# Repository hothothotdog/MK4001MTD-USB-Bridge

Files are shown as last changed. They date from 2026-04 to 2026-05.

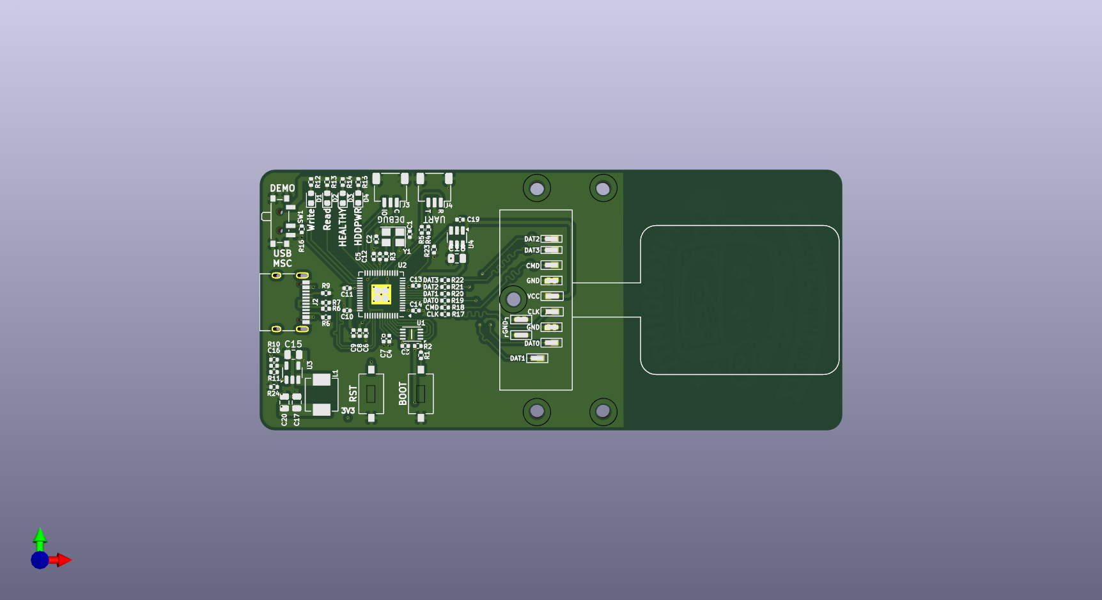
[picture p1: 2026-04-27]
hardware/MK4001MTD_3D-f.png

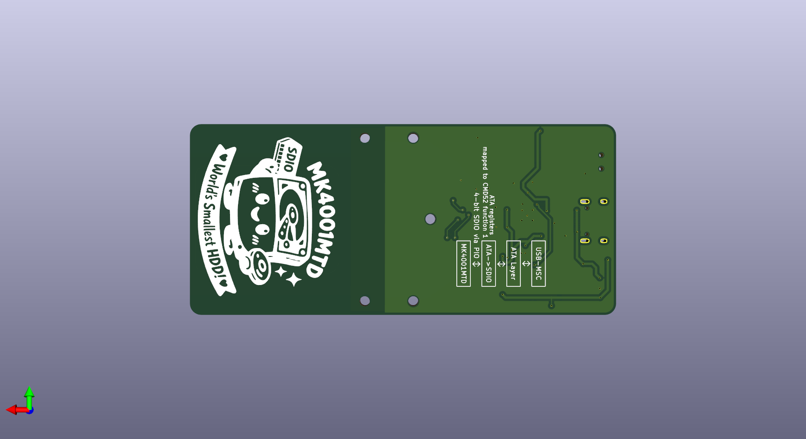
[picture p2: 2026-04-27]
hardware/MK4001MTD_3D-B.png

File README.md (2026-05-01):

This repository has moved to [https://codeberg.org/hothothotdog/MK4001MTD-USB-Bridge](https://codeberg.org/hothothotdog/MK4001MTD-USB-Bridge)

This GitHub copy is a frozen archive. New commits, issues, and pull requests should go to Codeberg.

---

Budget friendly changes to the PCB. Modified the PCB from 4-layers and 11cm long (about $70) to under 10cm and 2-layers which puts this in the $5 cost range at jlcpcb 

Schematic changes:
   - TLV62569DBV 
   Filter caps changed to higher value (as per datasheet recommendation)
   Voltage divider changed from 112K 25.3K (3.2v out) to sensible values 270K 60K (3.33v out)
   - Leds
   Current limiters set to 1mA (plenty bright enough)
   - Crystal 12MHz
   Changed 27pf caps to correct capacitance of 10pF each
   - NOR Flash
   Changed part to correct winbond W25Q16JVUXIQ
   Package changed to the correct DFN 3x2mm 

   new kicad files uploaded (27-4-2026) + ibom + images + pdf
   
# MK4001MTD USB Bridge

**RP2040 Pico firmware that bridges a Toshiba MK4001MTD 0.85" SDIO microdrive as a USB Mass Storage device.**
_DSC1170
_DSC1354

The MK4001MTD is a 4 GB Microdrive originally used in the Nokia N91 music phone and some other devices, like MP3 players or USB drives, back when flash storage was still quite expensive.

You might have seen introductions claiming this drive uses the MMC protocol, but that’s actually incorrect. I’ve been investigating this for a while: I tried building an 8-bit MMCplus card reader and tested different SD/MMC readers without success. As a last resort, I bought a Nokia N91 to capture logic traces and confirm what protocol it actually uses.

Here is the photo when I was trying to use it with my 8bit-MMCPlus reader board, and it turns out it is not MMC :(
_DSC0484

So I end up getting N91 to collect traces:
_DSC1093
_DSC1131

Unlike standard ATA/CF Microdrives, it uses an SDIO interface with ATA commands tunneled through CMD52/CMD53. No existing driver supports this protocol, so this firmware implements the full stack from scratch.

This surprised me, because there is an SDIO-to-ATA standard called CE-ATA. But if you look closely at the release timeline, CE-ATA came later than this drive. As a result, this drive relies entirely on SDIO commands, and CE-ATA is not available. CE-ATA has two new cmd CMD60/CMD61 and utilize CMD12/39, but you can see from the traces it is not using any of those.  

The second hardware point to mention is that another piece of misinformation floating around—claiming it’s an 8-bit MMCPlus card—is not only untrue, but the pinout doesn’t follow the MMC standard either. You can find the Nokia N91 service manual with some documentation on the pinout: while the pin numbering follows the MMCPlus standard, the pin mapping does not. This is an important detail if you’re wiring it yourself: it uses the same MMC connector, but the pin mapping is different, more in the Hardware section.

Finally, note that this is co-developed with Claude/OpenClaw. I collected the logic traces manually and set up a closed-loop test station for OpenClaw to iterate on development—analyzing the traces and implementing features. The documentation will mostly be written by Claude; I’ll add my notes inline as well. I’ve also read and double-checked the documentation myself, and it should be reliable and easy to follow.

For insights into the analytics on N91 trace, it is under /docs/N91_TRACE_ANALYSIS.md, I've also put the N91 service manual there along with the raw logic traces.

See more in the blog post here: [https://www.willwhang.dev/Reading-MK4001MTD/](https://www.willwhang.dev/Reading-MK4001MTD/)  
See it in activity here: [https://youtu.be/GC4xil3_Bbc](https://youtu.be/GC4xil3_Bbc)

## Status

Fully functional USB mass storage with PIO-accelerated reads/writes and idle power management.

| Metric | Value |
|---|---|
| Read speed | 550 kB/s |
| Write speed | 364 kB/s |
| Capacity | 3.75 GB (7,862,400 sectors) |
| Filesystem | FAT32 verified (mount/unmount/fsck clean) |
| Data integrity | Write+readback MD5 verified |
| Idle standby | 1 second timeout → STANDBY IMMEDIATE |

## How It Works

### Architecture

```
USB Host ←→ USB MSC (TinyUSB) ←→ ATA Layer ←→ SDIO Layer (PIO) ←→ MK4001MTD
```

The firmware has four layers:

1. **USB MSC** (`msc_device.c`) — TinyUSB Mass Storage Class. Translates SCSI READ(10)/WRITE(10) into ATA sector operations. EP buffer is 8192 bytes, batching up to 16 sectors per USB transfer. Activity LEDs on GP9 (TX/write) and GP10 (RX/read). Tracks last I/O timestamp for idle power management.

2. **ATA-over-SDIO** (`ata_sdio.c`) — Implements ATA commands (IDENTIFY, READ SECTORS, WRITE SECTORS) by writing to ATA registers mapped into SDIO function 1 address space via CMD52, and transferring sector data via CMD53. 3-tier retry logic at CMD, data, and ATA levels.

3. **PIO SDIO** (`sdio_pio.c`, `sdio.pio`) — Hardware-accelerated SDIO using RP2040's PIO peripheral. Three PIO programs share a single state machine via dynamic program swapping:
   - **CMD tx/rx** (26 instructions) — sends SDIO commands and receives responses
   - **DAT read** (13 instructions) — reads data blocks from 4-bit DAT bus via DMA
   - **DAT write** (16 instructions) — writes data blocks to 4-bit DAT bus via DMA, with built-in CRC status reception and busy-wait

4. **Bit-bang SDIO** (`sdio_hw.c`) — Software SDIO used only for card initialization at 400 KHz (before PIO is set up). All runtime I/O uses PIO.

Human notes: Interestingly, Claude was really reluctant to implement SDIO in PIO, and a lot of development cycles were wasted bouncing back and forth between PIO and bit-banging.

### The SDIO-ATA Protocol

The MK4001MTD presents itself as an SDIO card with one I/O function. Standard SDIO card initialization (CMD5/CMD3/CMD7) sets up the bus, then ATA registers are accessed through SDIO commands:

**Register access (CMD52):** Each ATA register is mapped to a function 1 address:

| Address | Register | Usage |
|---|---|---|
| 0x00 | DATA | CMD53 target for sector data |
| 0x01 | ERR/FEAT | Error (read) / Feature (write) |
| 0x02 | SECCOUNT | Sector count |
| 0x03 | LBA_LO | LBA bits 0-7 |
| 0x04 | LBA_MID | LBA bits 8-15 |
| 0x05 | LBA_HI | LBA bits 16-23 |
| 0x06 | DEV/HEAD | Device/Head + LBA bits 24-27 |
| 0x07 | CMD/STATUS | Command (write) / Status (read) |

**Data transfer (CMD53):** Sector data is transferred by issuing CMD53 in block mode targeting the DATA register (address 0x00). For multi-sector reads, a single CMD53 with `block_count=N` transfers N × 512 bytes in one SDIO multi-block transaction.

**Interrupt signaling:** The drive signals sector readiness by asserting an SDIO interrupt (INT_PENDING bit 1 in CCCR register 0x05). Reading the ATA STATUS register clears the interrupt.

### Read Path (Multi-Block PIO)

For a 16-sector read:

```
1. Write ATA registers via PIO CMD52:
     SECCOUNT=16, LBA_LO/MID/HI, DEV/HEAD=0xE0, CMD=0x20

2. Poll STATUS via CMD52 until DRQ (bit 3) is set

3. Swap PIO to DAT read program
4. Send CMD53: block_mode=1, fn=1, addr=0x0000, block_count=16

5. PIO DAT read: for each of the 16 blocks:
   a. Wait for start bit (all DAT lines low)
   b. DMA 1024 nibbles (512 bytes) from PIO RX FIFO to buffer
   c. Wait for SM to finish clocking CRC+end nibbles (poll SM PC)
   d. Repack nibbles → bytes in-place

6. Swap PIO back to CMD program
```

### Write Path (Multi-Block PIO)

For a 16-sector write:

```
1. Write ATA registers via PIO CMD52:
     SECCOUNT=16, LBA, DEV/HEAD=0xE0, CMD=0x30

2. Poll STATUS via CMD52 until DRQ (bit 3) is set
   (STATUS 0xD8 = BSY+DRQ treated as DRQ-ready, per N91 trace)

3. Swap PIO to DAT write program
4. Send CMD53: block_mode=1, fn=1, addr=0x0000, block_count=16

5. PIO DAT write: for each of the 16 blocks:
   a. Precompute CRC16-CCITT per DAT line (4 independent CRCs)
   b. Build nibble stream: start(0x0) + data(1024 nibbles) + CRC(16) + end(0xF)
   c. DMA nibble stream to PIO TX FIFO
   d. PIO clocks out all nibbles, then:
      - Switches DAT to input
      - Clocks 16 cycles for CRC status from card
      - Polls DAT0 until card releases busy
      - Fires IRQ 0 to signal block completion

6. Swap PIO back to CMD program
```

### PIO Program Swapping

The RP2040 PIO has 32 instruction slots per block. Our three programs total 55 instructions, so they can't coexist. Instead, a single SM0 on PIO0 is used, and programs are swapped by writing directly to PIO instruction memory:

```c
static void load_program_raw(const pio_program_t *program) {
    for (uint i = 0; i < program->length; i++)
        pio->instr_mem[FIXED_OFFSET + i] = program->instructions[i];
}
```

This bypasses the SDK's `pio_add_program`/`pio_remove_program` allocator. Program swap takes ~1 µs. Each swap is followed by a program-specific reinit that sets pin mappings, shift direction, and clock divider.

### Power Management

Analysis of Nokia N91 logic traces reveals aggressive power management:

- **Idle mode:** STANDBY IMMEDIATE (0xE0) every **~7.5 seconds**, even with no I/O. Each standby triggers full SDIO re-initialization (CMD5 retry → CMD3 → CMD7 → CCCR setup). 28 standby cycles observed in one idle session.
- **Active mode:** Standby issued between bursts of I/O (24 cycles during USB drive file operations).
- No other power commands (IDLE, SLEEP, CHECK POWER MODE) or CCCR power register accesses observed.

The firmware replicates this behavior with a configurable idle timeout:

```c
#define IDLE_STANDBY_MS 5000  // in main.c
```

Two paths trigger HDD power gating:

1. **Idle timeout** (5 seconds) — main loop detects no I/O activity
2. **USB suspend** — host suspends the USB port

Both paths send ATA STANDBY IMMEDIATE (0xE0) to flush the write cache and park heads, then cut power via GP9.

**Wake sequence** (triggered by first READ/WRITE after gate):
1. Power on HDD, wait 500ms for rail settling
2. PIO-based SDIO reinit: CMD5 (OCR) → 10ms settle → CMD3 (RCA) → CMD7 (select)
3. Switch to fast PIO clock, configure CCCR via CMD52 (4-bit bus, 512B blocks, fn1 enable)
4. Poll fn1 ready (CCCR IO_READY bit 1)
5. N91-style 30ms DRDY status poll until drive is ATA-ready

### Bad Sector Handling

When a multi-sector transfer hits a bad sector:
1. Chunk read fails → error recovery (IO_ABORT + fn1 reset, ~500ms)
2. Falls back to per-sector I/O to identify the failing block precisely
3. The ATA layer waits long enough to capture the final `STATUS/ERROR` bits instead of collapsing the failure into a generic `DRQ timeout`
4. Bad sector LBA cached → subsequent access fails quickly without re-hammering the drive
5. Any unrecovered block fails the SCSI command immediately with `MEDIUM ERROR`

On the known failing root-directory sector (`LBA 1952`), the drive now reports the real ATA result:

```text
READ: ST=0x51 ERR ERR=0x40 UNC LBA=1952
FAST-RD: ST=0x51 ERR ERR=0x40 UNC LBA=1952
```

## Building

### Prerequisites

- Raspberry Pi Pico SDK
- ARM toolchain (`arm-none-eabi-gcc`)
- CMake

### Build & Flash

```bash
cd /home/pi/mk4001_bridge/build
cmake ..
make -j4

sudo openocd -f interface/cmsis-dap.cfg -f target/rp2040.cfg \
  -c "adapter speed 1000" -c "init" -c "reset halt" -c "sleep 200" \
  -c "program /home/pi/mk4001_bridge/build/mk4001_bridge.elf verify" \
  -c "reset run" -c "exit"
```

### Hardware Wiring

| Pico GPIO | Function | Notes |
|---|---|---|
| GP2 | SDIO_CLK | Host clock output |
| GP3 | SDIO_CMD | Bidirectional command line |
| GP4 | SDIO_DAT0 | Data bit 0 |
| GP5 | SDIO_DAT1 | Data bit 1 |
| GP6 | SDIO_DAT2 | Data bit 2 |
| GP7 | SDIO_DAT3 | Data bit 3 |
| GP9 | HDD_EN | Drive power enable (HIGH=on) |
| GP12 | UART TX | Debug output @ 115200 |
| GP13 | UART RX | Debug input |
| GP16 | LED: HDD Power | Active low |
| GP17 | LED: HDD Healthy | Active low |
| GP18 | LED: Read | Active low |
| GP19 | LED: Write | Active low |

**Note:** GP0 and GP1 are dead on this specific Pico unit. All SDIO pin assignments are shifted +2.

Human notes: Claude was wrong here because it didn’t realize that GP0 and GP1 were being used for the UART terminal in its build configuration. It kept forgetting this, to the point where I just moved the SDIO GPIOs off that UART.

HDD_PWR isn’t necessary. You don’t have to power-cycle the drive to use it; it’s more of a development convenience for resetting the HDD when a lot of things are hard-coded. That said, if you want power savings, you can use that signal, but it can handle warm reset without any issue.

You’ll see debug messages over UART. They’re not going through USB-CDC because it was easier for Claude to set up a separate UART-to-USB logging link that doesn’t disconnect or become unstable during early development.  
Here is a example of the log:

```
========================================
  MK4001MTD USB Bridge v0.11
  SDIO-ATA → USB Mass Storage (PIO)
========================================

[MAIN] Pre-delay 5000ms...
[PIO] Init OK: clkdiv=3.12 (~10.0 MHz), CMD@0
[MAIN] Power cycling HDD...
[SDIO] HDD power OFF
[SDIO] HDD power ON
[MAIN] SDIO init (PIO)...
[SDIO] CMD5 ready (OCR=0x901F8000)
[SDIO] RCA=0x0001
[SDIO] fn1 ready (attempt 0)
[MAIN] ATA IDENTIFY...
[ATA] IDENTIFY complete
Model:    [TOSHIBA MK4001MTD]
Serial:   [           763B004HA]
Firmware: [VH173A]
Sectors:  7862400 (3839 MB)
SMART:    not supported (supported=0, enabled=0)
IDENTIFY: W0=0040 W47=0000 W49=0000 W59=0000
  ATA W80=0000  Cmd W82=0000 W83=0000 W84=0000
  En  W85=0000 W86=0000 W87=0000  W89=0008 W128=0001

[DIAG] === Drive Diagnostics ===
[DIAG] Standard SMART: not supported (IDENTIFY W82 bit0 = 0)
[DIAG] Toshiba vendor CMD 0xC2:
  FEAT=0x01 unknown_01                       → SC=00 LBA=02/00/00 ST=50
  FEAT=0x02 unknown_02                       â SC=00 LBA=02/00/00 ST=50
  FEAT=0x03 unknown_03                       → SC=00 LBA=02/00/00 ST=50
  FEAT=0x04 unknown_04                       → SC=00 LBA=02/00/00 ST=50
  FEAT=0x10 diag_10 (LBA_LO varies)          → SC=00 LBA=00/00/00 ST=50
  FEAT=0x11 diag_11                          → SC=00 LBA=00/00/00 ST=50
  FEAT=0x12 diag_12 (LBA_LO varies)          → SC=00 LBA=01/00/00 ST=50
  FEAT=0x20 query_20 (N91: SC=0xFF always)   → SC=FE LBA=00/FF/00 ST=50
  FEAT=0x21 query_21 (N91: SC varies per boot) → SC=1B LBA=00/FF/00 ST=50

[MAIN] MBR: valid 0x55AA
[MAIN] Warming up...
[MAIN] PIO OK, STATUS=0x50
[MAIN] Drive: 7862400 sectors (3839 MB)
[MAIN] Ready.
[PWR] Idle 5000ms → STANDBY + power gate
[PWR] STANDBY IMMEDIATE → power gate
[SDIO] HDD power OFF
```

Finally, here’s the wiring to the actual drive.  
_DSC1176-2
Here is a crop from the N91 schematic, you can map the pin number also.


Side note that this is a 3V drive but I think 3.3V is fine, mostly it is to save some level shifting work.  

HW specifically designed for this drive is under /hardware!


## Source Files

| File | Lines | Purpose |
|---|---|---|
| `main.c` | 210 | Init, idle standby, USB suspend/resume |
| `msc_device.c` | 400 | USB MSC callbacks, power gate wake, bad sector cache |
| `ata_sdio.c` | 390 | ATA commands, error recovery, vendor diagnostics |
| `sdio_pio.c` | 635 | PIO SDIO: CMD52, CMD53 read/write, program swap, CRC16 |
| `sdio_hw.c` | 45 | Pin init + HDD power control |
| `sdio.pio` | 200 | PIO assembly + C SDK init helpers |
| `led.h` | 37 | LED helpers (GP16–GP19, active low) |
| `usb_descriptors.c` | 77 | USB device/config/string descriptors |
| `tusb_config.h` | 20 | TinyUSB config (MSC, 32KB EP buffer) |

## Version History

| Version | Read | Write | Key Change |
|---|---|---|---|
| v0.1–v0.3 | 105 kB/s | 93 kB/s | Bit-bang SDIO, CRC16, retry logic |
| v0.5 | 374 kB/s | — | Single-SM PIO, direct instruction memory swap |
| v0.6 | 583 kB/s | 93 kB/s | Multi-block CMD53 reads, CRC clock drain fix |
| v0.8 | 588 kB/s | 274 kB/s | PIO writes, OSR flush fix |
| v0.9 | 475 kB/s | 371 kB/s | 64-sector chunks, CRC16 read verification |
| v0.10 | 453 kB/s | 329 kB/s | LED remap, HDD EN pin, UART on GP12/GP13 |
| **v0.11** | **~450 kB/s** | **~340 kB/s** | **HDD power gate, PIO wake, bad sector sense, USB suspend** |

## Testing

```bash
# Check device appeared
lsblk -dno NAME,MODEL | grep MK4001

# Filesystem test — mount, copy files, verify
sudo mount /dev/sdX1 /mnt/mk4001
cp /tmp/testfile /mnt/mk4001/
sync
md5sum /tmp/testfile /mnt/mk4001/testfile    # should match
sudo umount /mnt/mk4001

# Speed benchmarks (raw device, do NOT mount first — will corrupt filesystem)
# Use a safe offset past the filesystem or an unpartitioned drive
sudo dd if=/dev/sdX of=/dev/null bs=64k count=128 iflag=direct     # read
sudo dd if=/dev/zero of=/dev/sdX bs=64k count=64 oflag=direct seek=1024  # write (offset past FS)
```

Human notes here, fun fact: When it first starts to do speed testing, it actually dd directly to the drive and damage the filesystems..... Thankfully it doesn't matter that much here during the developments but always keep in mind when you handle OpenClaw your setup.

## License

I don't care.

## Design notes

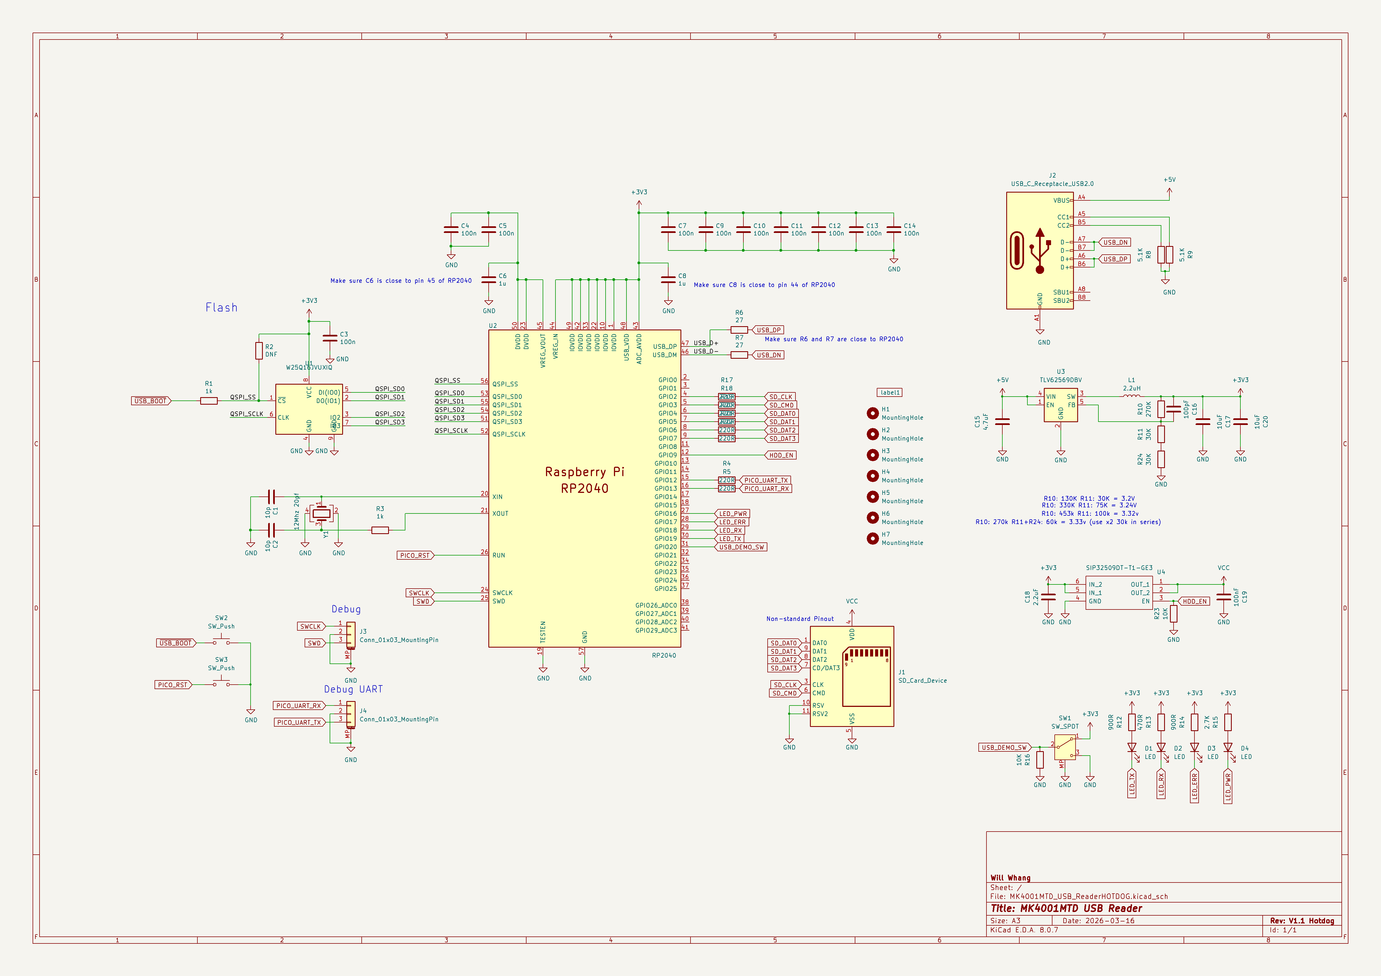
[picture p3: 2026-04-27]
hardware/SCH.png

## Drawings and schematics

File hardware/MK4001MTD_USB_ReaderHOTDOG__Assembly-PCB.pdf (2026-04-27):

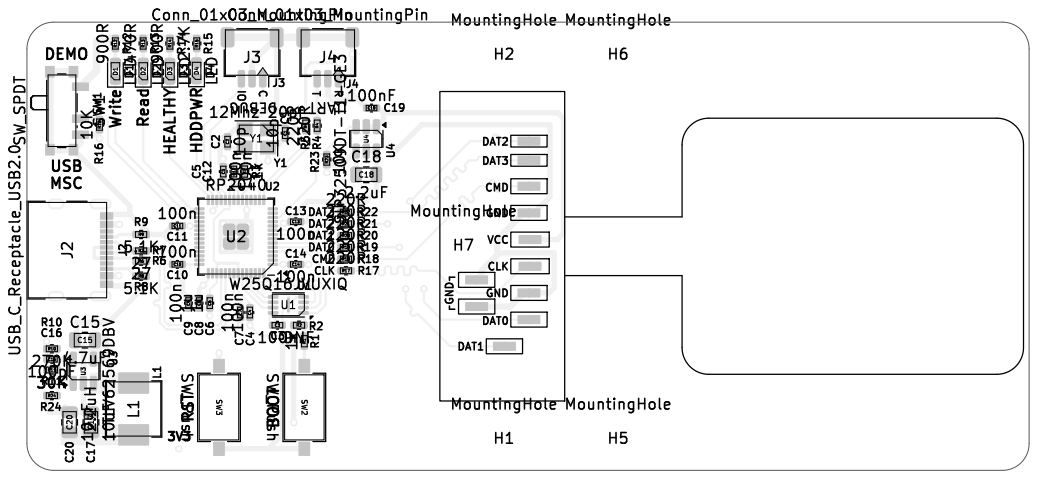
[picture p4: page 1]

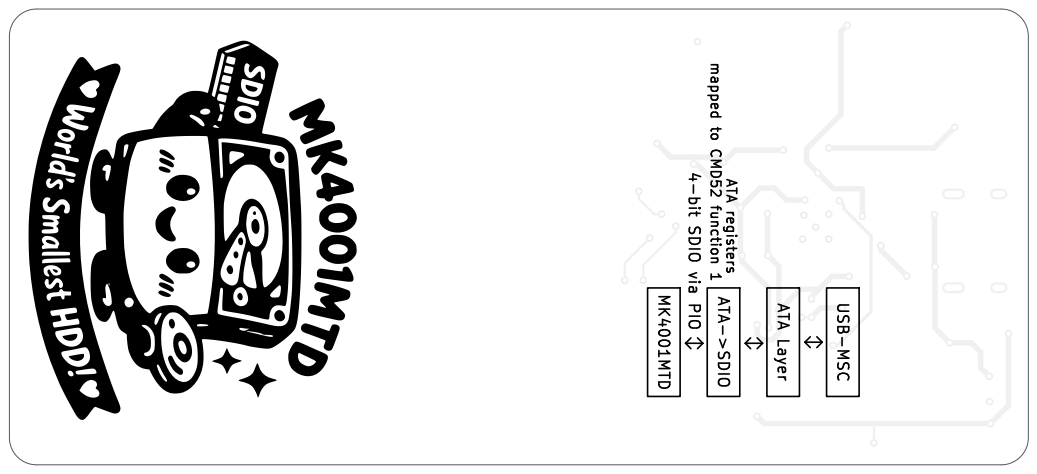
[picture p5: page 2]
D Date: 2026-03-16 KiCad; E.D.A. 8.0.7 Size: A4; Rev: v1.1; HOTDOG; Id: 1/1 Title: MK4001MTD USB Reader File: MK4001MTD_USB_ReaderHOTDOG.kicad_pcb Sheet: Black; And; White; BOT Will Whang Board2Pdf:; Black; BOT -; Page 2/2

USB-MSC ATA registers mapped to CMD52 function 1 ATA Layer MK4001MTD ATA->SDIO 4-bit SDIO via PIO

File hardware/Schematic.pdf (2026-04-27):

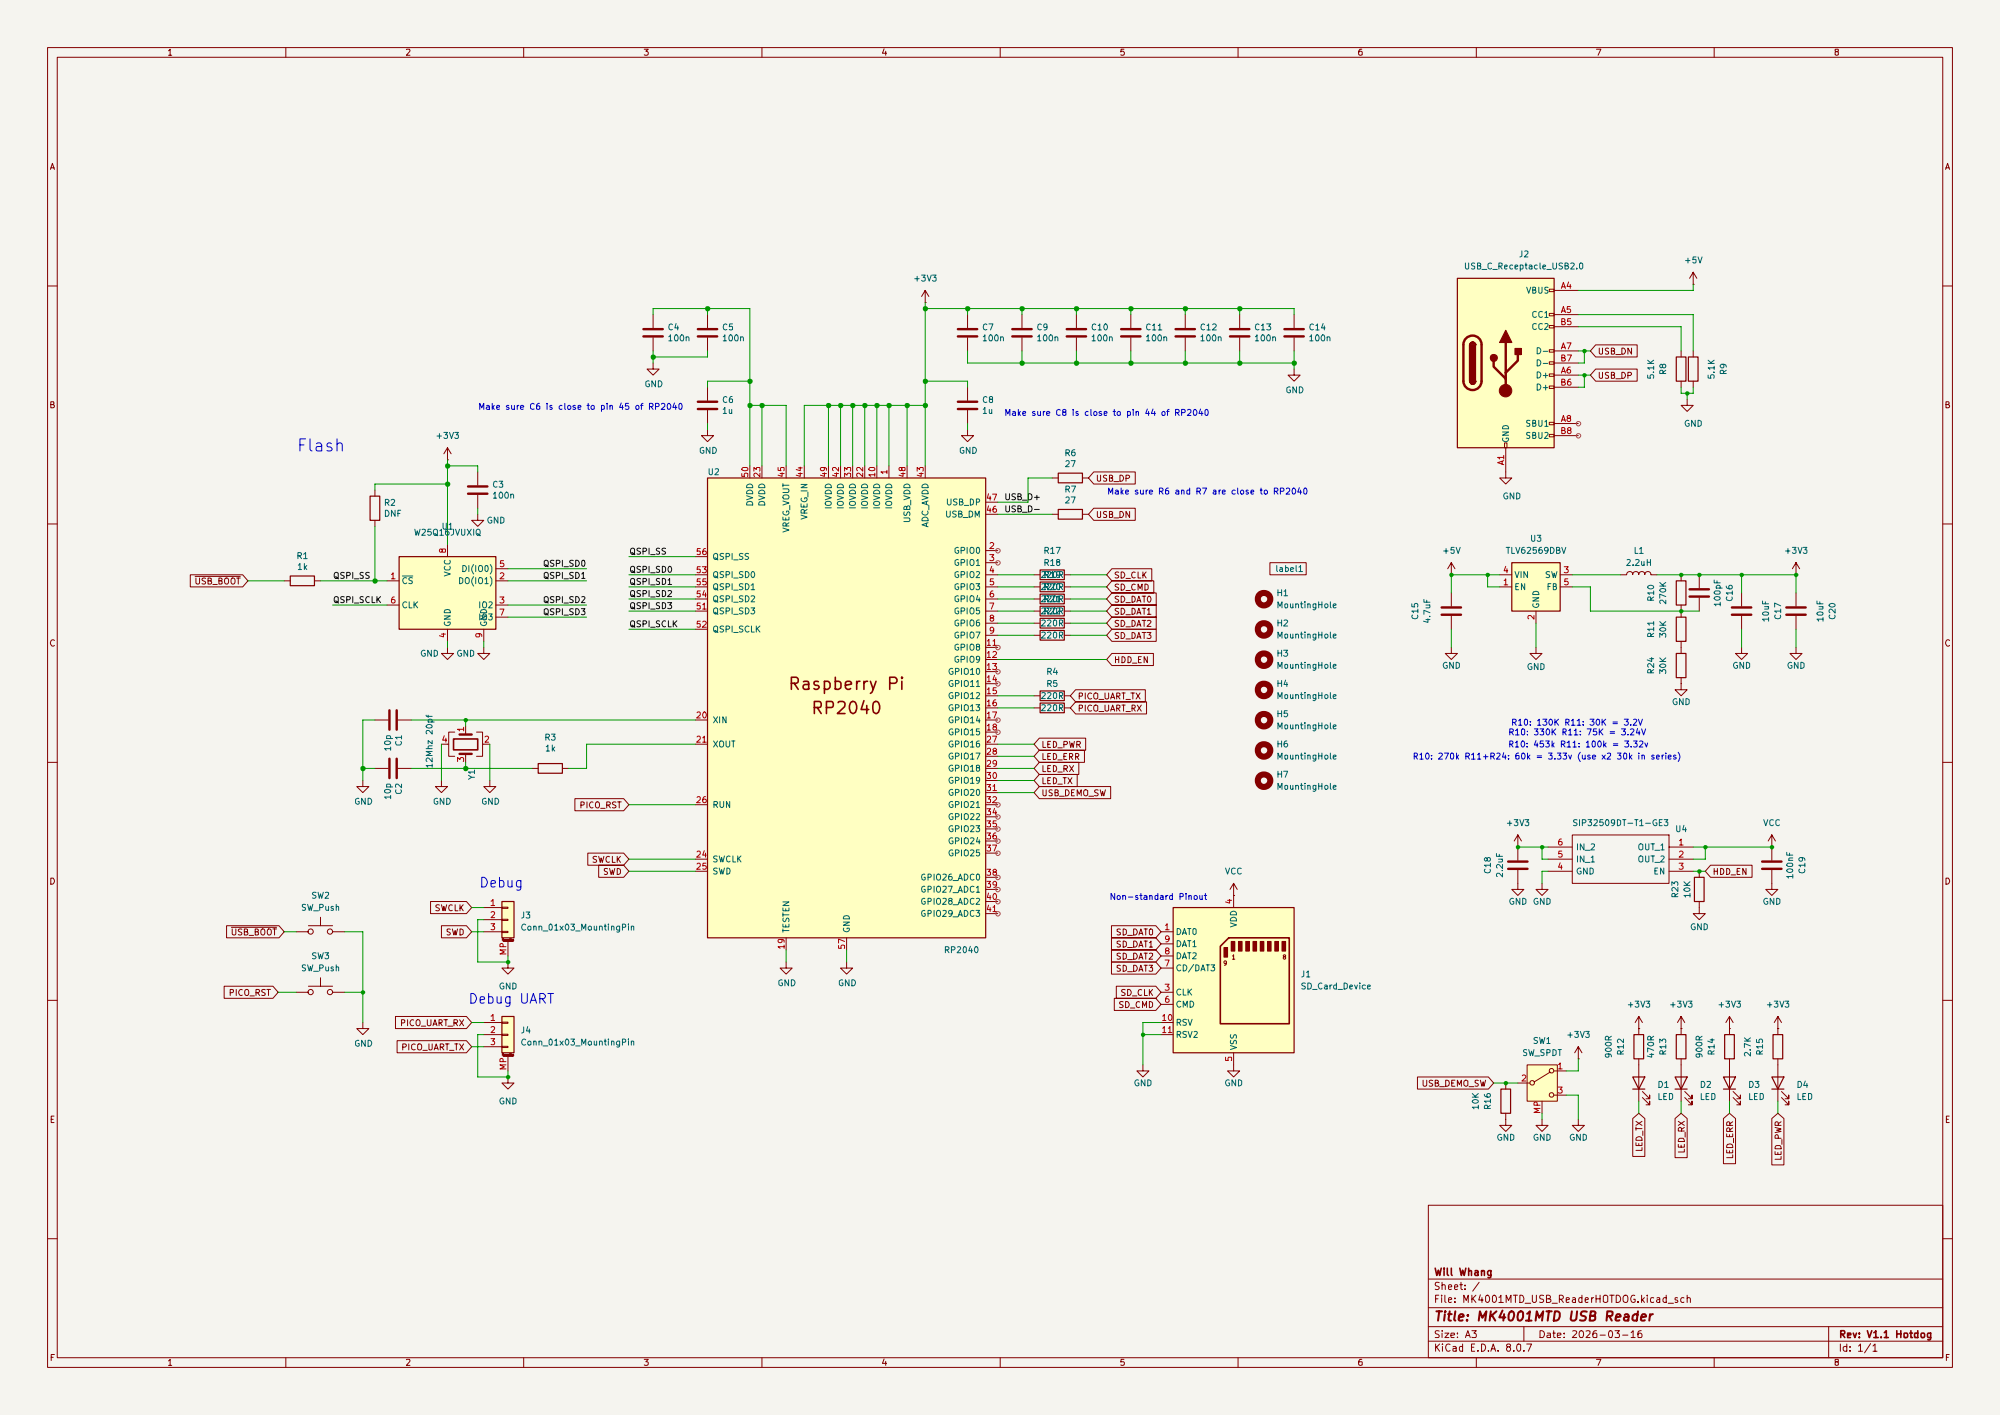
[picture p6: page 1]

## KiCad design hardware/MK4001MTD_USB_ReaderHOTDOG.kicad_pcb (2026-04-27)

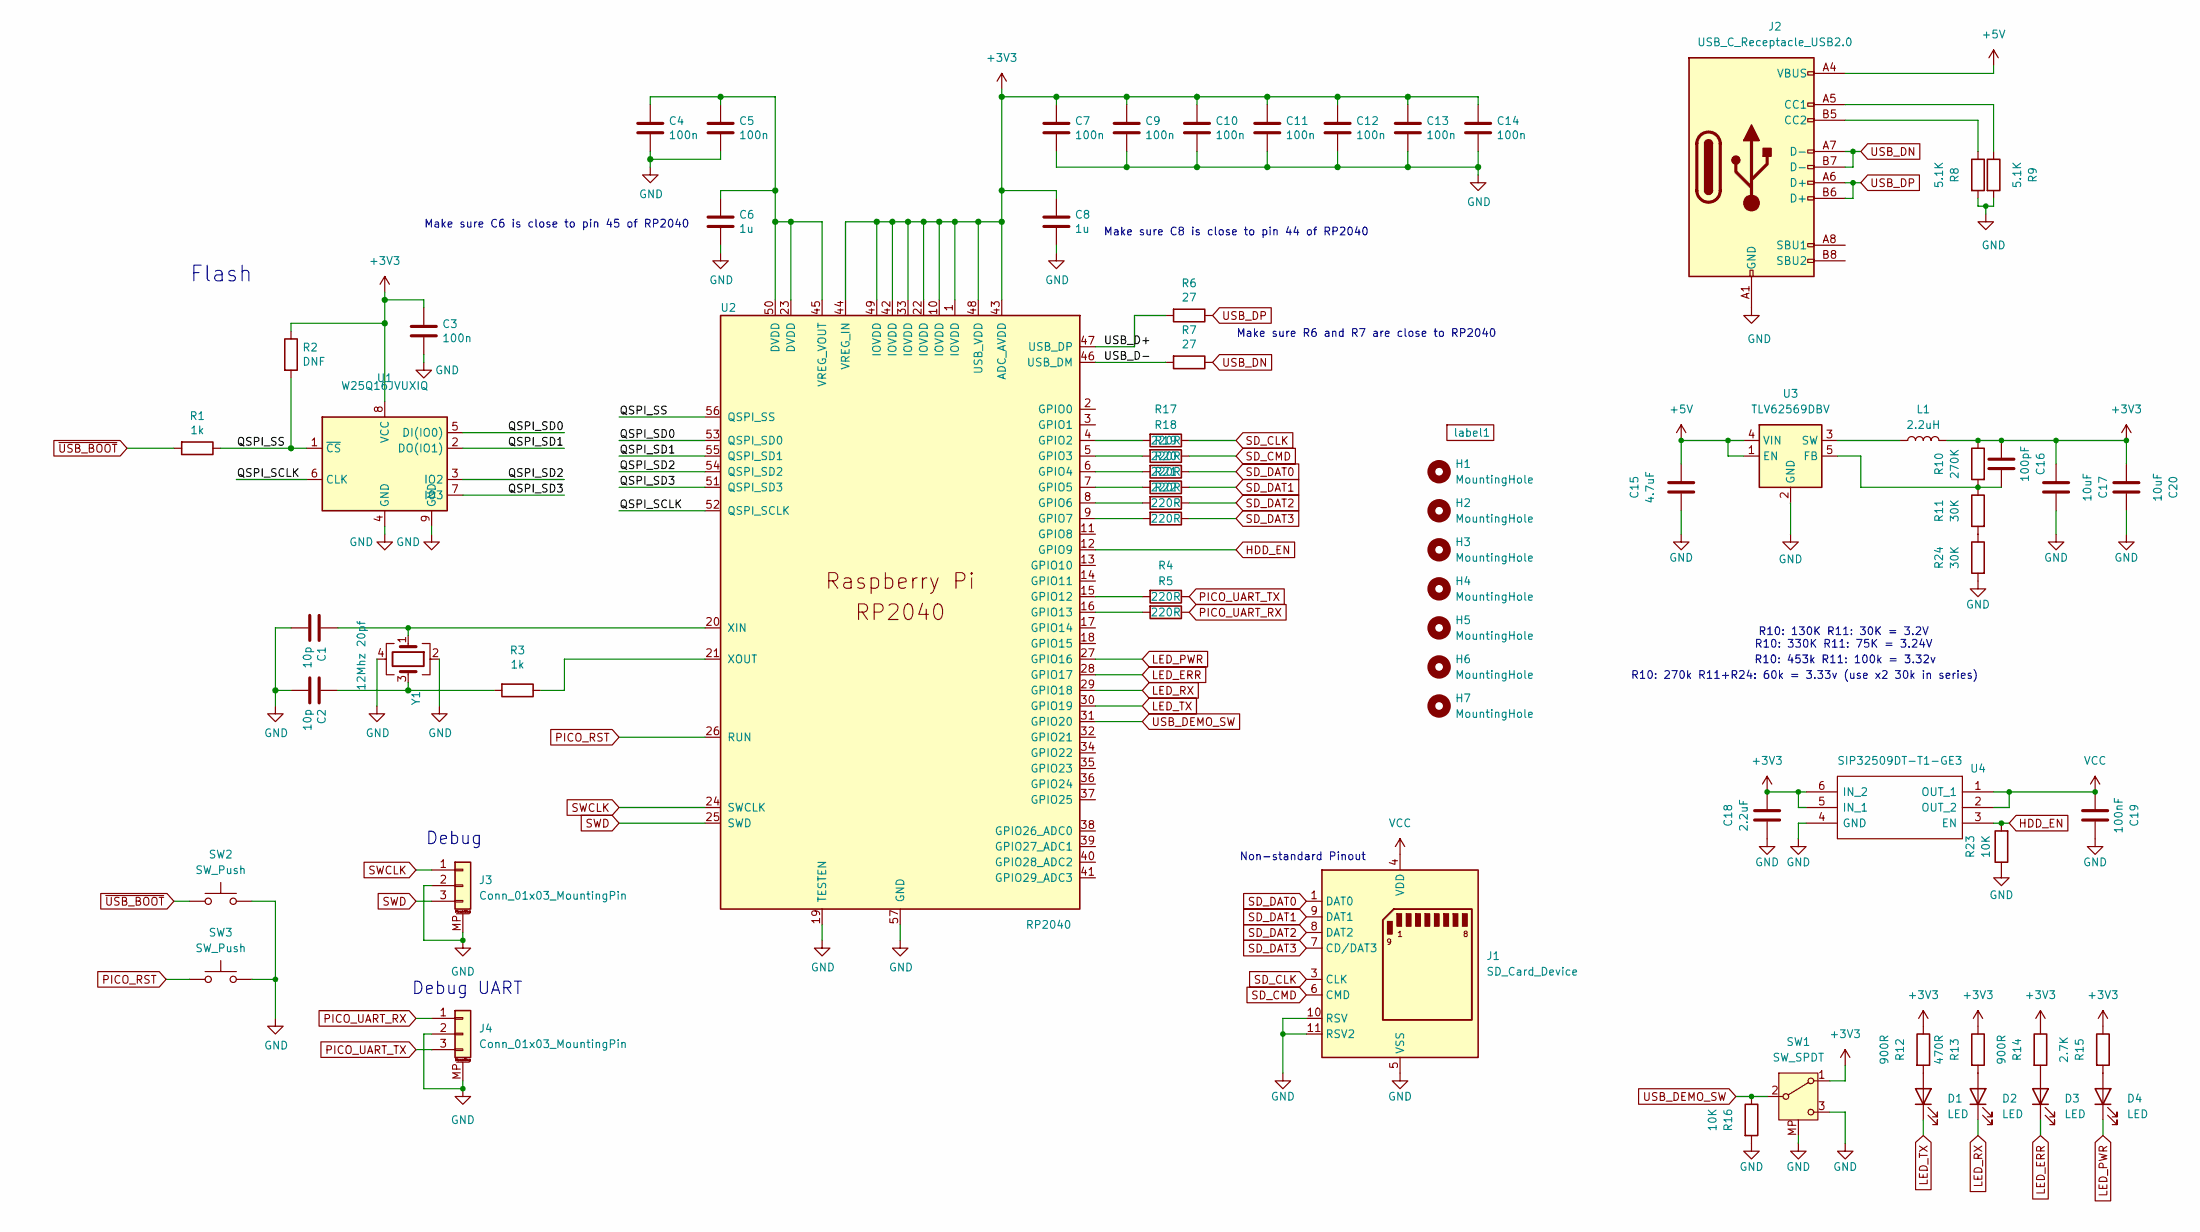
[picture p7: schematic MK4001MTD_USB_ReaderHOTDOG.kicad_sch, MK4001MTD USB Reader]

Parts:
C1, C2: 10p; C_0402_1005Metric
C3, C4, C5, C7, C9, C10, C11, C12, C13, C14: 100n; C_0402_1005Metric
C6, C8: 1u; C_0402_1005Metric
C15: 4.7uF; C_0805_2012Metric
C16: 100pF; C_0402_1005Metric
C17, C20: 10uF; C_0805_2012Metric
C18: 2.2uF; C_0805_2012Metric
C19: 100nF; C_0402_1005Metric
D1, D2, D3, D4: LED; LED_0603_1608Metric
H1, H2, H3, H4, H5, H6, H7: MountingHole; MountingHole_2.2mm_M2
J1: SD_Card_Device; MK4001MTD
J2: USB_C_Receptacle_USB2.0; USB_C_Receptacle_XKB_U262-16XN-4BVC11
J3, J4: Conn_01x03_MountingPin; JST_SH_SM03B-SRSS-TB_1x03-1MP_P1.00mm_Horizontal
L1: 2.2uH; L_Vishay_IHLP-2020
R1, R3: 1k; R_0402_1005Metric
R2: DNF; R_0402_1005Metric
R4, R5, R17, R18, R19, R20, R21, R22: 220R; R_0402_1005Metric
R6, R7: 27; R_0402_1005Metric
R8, R9: 5.1K; R_0402_1005Metric
R10: 270K; R_0402_1005Metric
R11, R24: 30K; R_0402_1005Metric
R12, R14: 900R; R_0402_1005Metric
R13: 470R; R_0402_1005Metric
R15: 2.7K; R_0402_1005Metric
R16, R23: 10K; R_0402_1005Metric
SW1: SW_SPDT; SW_SPDT_PCM12
SW2, SW3: SW_Push; SW_Tactile_SPST_NO_Straight_CK_PTS636Sx25SMTRLFS
U1: W25Q16JVUXIQ; Winbond_USON-8-1EP_3x2mm_P0.5mm_EP0.2x1.6mm
U2: RP2040; RP2040-QFN-56
U3: TLV62569DBV; SOT-23-5
U4: SIP32509DT-T1-GE3; SOT-23-6; Mouser Part Number 78-SIP32509DT-T1-GE3
Y1: 12Mhz 20pf; Crystal_SMD_3225-4Pin_3.2x2.5mm
label1: QRCode

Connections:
+3V3: C3.1, C7.1, C8.1, C9.1, C10.1, C11.1, C12.1, C13.1, C14.1, C16.1, C17.1, C18.2, C20.1, L1.2, R2.1, R10.1, R12.1, R13.1, R14.1, R15.1, SW1.1 (A), U1.8 (VCC), U2.1 (IOVDD), U2.10 (IOVDD), U2.22 (IOVDD), U2.33 (IOVDD), U2.42 (IOVDD), U2.43 (ADC_AVDD), U2.44 (VREG_IN), U2.48 (USB_VDD), U2.49 (IOVDD), U4.5 (IN_1), U4.6 (IN_2)
+5V: C15.2, J2.A4 (VBUS), J2.A9 (VBUS), J2.B4 (VBUS), J2.B9 (VBUS), U3.1 (EN), U3.4 (VIN)
/QSPI_SCLK: U1.6 (CLK), U2.52 (QSPI_SCLK)
/QSPI_SD0: U1.5 (DI(IO0)), U2.53 (QSPI_SD0)
/QSPI_SD1: U1.2 (DO(IO1)), U2.55 (QSPI_SD1)
/QSPI_SD2: U1.3 (IO2), U2.54 (QSPI_SD2)
/QSPI_SD3: U1.7 (IO3), U2.51 (QSPI_SD3)
/QSPI_SS: R1.1, R2.2, U1.1 (~CS), U2.56 (QSPI_SS)
/USB_D+: R6.2, U2.47 (USB_DP)
/USB_D-: R7.2, U2.46 (USB_DM)
GND: C1.2, C2.2, C3.2, C4.2, C5.2, C6.2, C7.2, C8.2, C9.2, C10.2, C11.2, C12.2, C13.2, C14.2, C15.1, C17.2, C18.1, C19.2, C20.2, J1.2 (VSS), J1.5 (VSS), J1.10 (RSV), J1.11 (RSV2), J2.A1 (GND), J2.A12 (GND), J2.B1 (GND), J2.B12 (GND), J3.2, J3.MP (MountPin), J4.2, J4.MP (MountPin), R8.2, R9.2, R16.2, R23.1, R24.2, SW1.3 (C), SW1.MP, SW2.2, SW3.2, U1.4 (GND), U1.9 (GND), U2.19 (TESTEN), U2.57 (GND), U3.2 (GND), U4.4 (GND), Y1.2, Y1.4
HDD_EN: R23.2, U2.12 (GPIO9), U4.3 (EN)
LED_ERR: D3.1 (K), U2.28 (GPIO17)
LED_PWR: D4.1 (K), U2.27 (GPIO16)
LED_RX: D2.1 (K), U2.29 (GPIO18)
LED_TX: D1.1 (K), U2.30 (GPIO19)
unnamed: C2.1, R3.2, Y1.3
unnamed: D1.2 (A), R12.2
unnamed: D2.2 (A), R13.2
unnamed: D3.2 (A), R14.2
unnamed: D4.2 (A), R15.2
unnamed: J2.A5 (CC1), R9.1
unnamed: J2.B5 (CC2), R8.1
unnamed: R11.2, R24.1
unnamed: R17.2, U2.4 (GPIO2)
unnamed: R18.2, U2.5 (GPIO3)
unnamed: R19.2, U2.6 (GPIO4)
unnamed: R20.2, U2.7 (GPIO5)
unnamed: R21.2, U2.8 (GPIO6)
unnamed: R22.2, U2.9 (GPIO7)
unnamed: R4.2, U2.15 (GPIO12)
unnamed: R5.2, U2.16 (GPIO13)
unnamed: C4.1, C5.1, C6.1, U2.23 (DVDD), U2.45 (VREG_VOUT), U2.50 (DVDD)
unnamed: C1.1, U2.20 (XIN), Y1.1
unnamed: R3.1, U2.21 (XOUT)
unnamed: C16.2, R10.2, R11.1, U3.5 (FB)
unnamed: L1.1, U3.3 (SW)
PICO_RST: SW3.1, U2.26 (RUN)
PICO_UART_RX: J4.1, R5.1
PICO_UART_TX: J4.3, R4.1
SD_CLK: J1.3 (CLK), R17.1
SD_CMD: J1.6 (CMD), R18.1
SD_DAT0: J1.1 (DAT0), R19.1
SD_DAT1: J1.9 (DAT1), R20.1
SD_DAT2: J1.8 (DAT2), R21.1
SD_DAT3: J1.7 (CD/DAT3), R22.1
SWCLK: J3.1, U2.24 (SWCLK)
SWD: J3.3, U2.25 (SWD)
USB_DEMO_SW: R16.1, SW1.2 (B), U2.31 (GPIO20)
USB_DN: J2.A7 (D-), J2.B7 (D-), R7.1
USB_DP: J2.A6 (D+), J2.B6 (D+), R6.1
VCC: C19.1, J1.4 (VDD), U4.1 (OUT_1), U4.2 (OUT_2)
~USB_BOOT: R1.2, SW2.1

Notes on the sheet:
R10: 453k R11: 100k = 3.32v
Debug UART
Make sure R6 and R7 are close to RP2040
Flash
Make sure C8 is close to pin 44 of RP2040
R10: 270k R11+R24: 60k = 3.33v (use x2 30k in series)
Debug
R10: 130K R11: 30K = 3.2V R10: 330K R11: 75K = 3.24V
Make sure C6 is close to pin 45 of RP2040
Non-standard Pinout

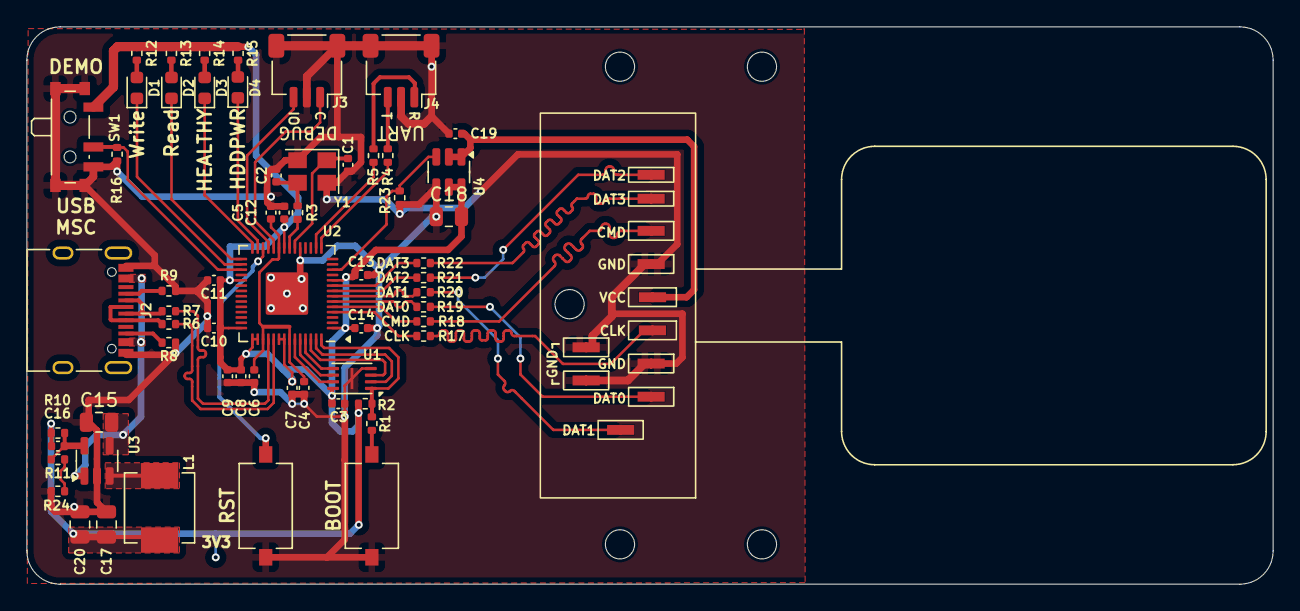
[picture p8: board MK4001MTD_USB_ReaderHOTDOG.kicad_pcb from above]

Board: 2 copper layers, 93.9 x 42.0 mm, 66 parts (0 on the bottom side), 53 nets.

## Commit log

2026-04-27 Project updated for all changes
    [MK4001MTD_USB_ReaderHOTDOG.kicad_pcb, MK4001MTD_USB_ReaderHOTDOG.kicad_sch]
2026-04-27 Update BOM for all changes
2026-04-27 Updated PCB
2026-04-27 Updated Gerbers
    [MK4001MTD_USB_ReaderHOTDOG-B_Cu.gbr, MK4001MTD_USB_ReaderHOTDOG-B_Mask.gbr, MK4001MTD_USB_ReaderHOTDOG-B_Paste.gbr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]
2026-04-27 Updated schematic
2026-04-27 u[dated pcb and zones
    [MK4001MTD_USB_ReaderHOTDOG.kicad_pcb]
